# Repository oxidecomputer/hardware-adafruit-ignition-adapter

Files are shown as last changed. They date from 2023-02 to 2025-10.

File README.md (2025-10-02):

# hardware-adafruit-ignition-adapter

## Description

Adapter board for the [Adafruit FT232H](https://www.adafruit.com/product/2264)
compatible with `iceprog` and the Samtec debug pinout we're using on our
designs.

## Ordering Information

Each release contains a file called `[CPN]_release_notes.txt` with ordering
instructions. Order PCBs through Sierra Circuits' [Turnkey
PRO](https://www.protoexpress.com/products/turnkey-pro/) fabrication and
assembly service.

## Release Information

Fabrication data follows the `[CPN]_rev[X]_v[Y]` naming convention, where
revision `rev[X]` and version `v[Y]` corresponds to the two numbers in Altium's
release version. Here's why:

- When we release the board in Altium 365, Altium tags the release with the
  suffix `[X].[Y]`

- However, Sierra Circuits only accepts a single revision number, which appears
  in their ordering system as `_rev[X]`.
  
- When we assemble the tapeout data package together for Sierra Circuits, we
  name the tapeout files `[CPN]_rev[X]_v[Y]` to maintain the mapping between
  Altium release and the out-of-band tapeout data package.

- When we order PCBs through Sierra Circuits, we specify the revision using the
  `[X]` number. This appears in Sierra's order system as `[CPN]_rev[X]`.

Essentially, we ignore the `[Y]` value and we increment the `[X]` in the Altium
release. In practice, however, the `[Y]` value in the Altium release ends up
getting incremented if we have to re-release something in Altium to correct data
export errors before submitting the release for fabrication (for example, to fix
missing drill files in the tapeout data package). If this sounds confusing, it's
because it is.

## Assembly

Follow the [assembly
instructions](https://github.com/oxidecomputer/hardware-adafruit-ignition-adapter/tree/main/assembly)
to assemble a complete Ignition programming dongle.

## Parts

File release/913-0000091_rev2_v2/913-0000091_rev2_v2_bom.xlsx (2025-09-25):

BOM: 913-0000091
Assembly Part Number/Revision: 913-0000091_rev2
Oxide Computer Company
 |  |  | 1
Item # | Quantity per board | Manufacturer Part # | Do Not Install | Reference designators | Vendor (optional) | Vendor Part Number (optional) | Value (optional) | Size / Footprint (optional) | Part description/ specs (optional, but recommended) | Manfacturer (optional)
1 | 1 | GRM155R61E105KA12D |  | C1 | DigiKey | 490-10017-1-ND | 1uF |  | CAP CER 1UF 25V X5R 0402 | Murata Electronics
2 | 2 | 22284110 |  | J1,J2 | DigiKey | WM50014-11-ND |  |  | CONN HEADER VERT 11POS 2.54MM | Molex
3 | 1 | TFC-105-02-L-D-A-K-TR |  | J3 | Mouser | 200-TFC10502LDAKTR |  |  | .050 X .050 TERMINAL STRIP | Samtec
4 | 1 | RMCF0402FT10K0 |  | R1 | Digikey | RMCF0402FT10K0CT-ND | 10k |  | RES 10K OHM 1% 1/16W 0402 | Stackpole
5 | 2 | RMCF0402FT15R0 |  | R2,R3 | Digikey | RMCF0402FT15R0CT-ND | 15 |  | RES 15 OHM 1% 1/16W 0402 | Stackpole
6 | 1 | SN74LVC1G07DCKR |  | U1 | Digikey | 296-8486-1-ND |  |  | IC BUFF NON-INVERT 5.5V SC-70-5 | Texas Instruments
END OF BOM

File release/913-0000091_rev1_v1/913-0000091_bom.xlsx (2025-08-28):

BOM: 913-0000091
Assembly Part Number/Revision: 913-0000091_rev1
Oxide Computer Company
 |  |  | 1
Item # | Quantity per board | Manufacturer Part # | Do Not Install | Reference designators | Vendor (optional) | Vendor Part Number (optional) | Value (optional) | Size / Footprint (optional) | Part description/ specs (optional, but recommended) | Manfacturer (optional)
1 | 11 | GRM155R61E105KA12D |  | C1,C2,C3,C4,C5,C6,C7,C8,C9,C10,C11 | DigiKey | 490-10017-1-ND | 1uF |  | CAP CER 1UF 25V X5R 0402 | Murata Electronics
2 | 7 | UCLAMP3301P.TCT |  | D1,D2,D3,D4,D5,D6,D7 | Mouser | 947-UCLAMP3301P.TCT |  |  | UCLAMP 1 LINE ESD PROTECTION | Semtech
3 | 2 | 22284110 |  | J1,J2 | DigiKey | WM50014-11-ND |  |  | CONN HEADER VERT 11POS 2.54MM | Molex
4 | 1 | TFC-105-02-L-D-A-K-TR |  | J3 | Mouser | 200-TFC10502LDAKTR |  |  | .050 X .050 TERMINAL STRIP | Samtec
5 | 4 | RMCF0402FT10K0 |  | R1,R6,R8,R9 | Digikey | RMCF0402FT10K0CT-ND | 10k |  | RES 10K OHM 1% 1/16W 0402 | Stackpole
6 | 5 | RMCF0402FT15R0 |  | R2,R3,R4,R5,R7 | Digikey | RMCF0402FT15R0CT-ND | 15 |  | RES 15 OHM 1% 1/16W 0402 | Stackpole
7 | 1 | SN74LVC1G07DCKR |  | U1 | Digikey | 296-8486-1-ND |  |  | IC BUFF NON-INVERT 5.5V SC-70-5 | Texas Instruments
8 | 5 | SN74LVC1T45DCKR |  | U2,U3,U4,U5,U6 | Digikey | 296-16844-1-ND |  |  | IC XLTR VL BIDIR SC-70-6 | Texas Instruments
END OF BOM

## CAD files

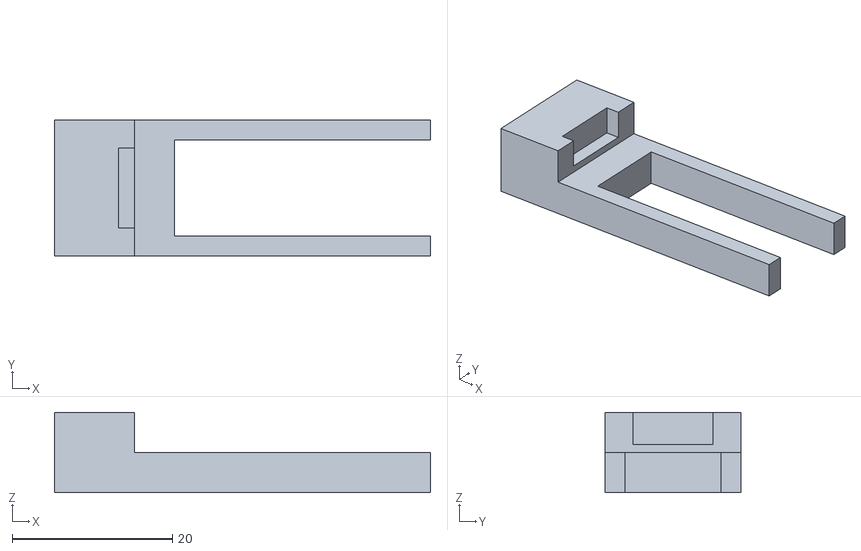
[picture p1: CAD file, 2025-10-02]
assembly/adafruit_soldering_fixture/adafruit_soldering_fixture.stl
47.0 x 17.0 x 10.0

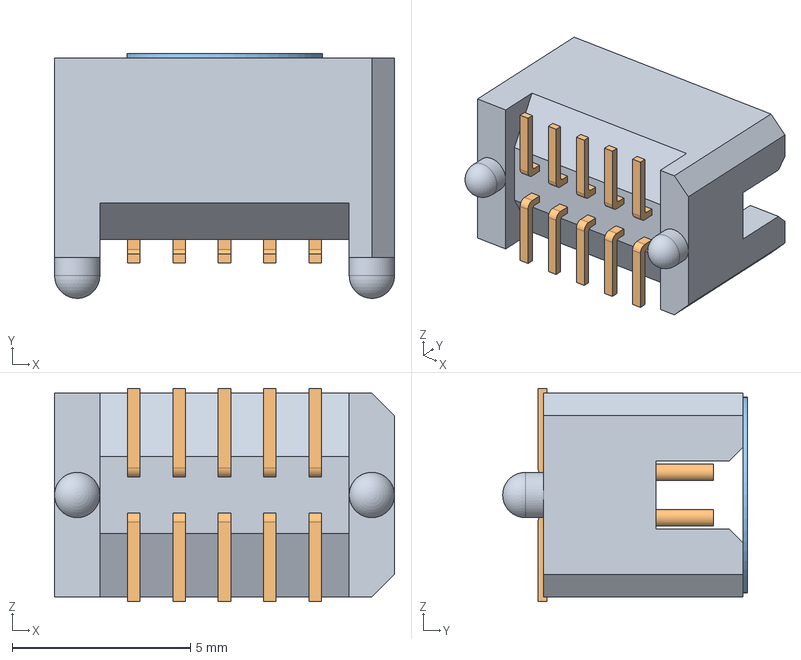
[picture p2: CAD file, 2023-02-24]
release/913-0000091_rev0/TFC-105-02-F-D-A-K.step
9.52 x 6.86 x 5.97 mm
_TFC-105-02-L-D-A-K_terminal
_TFC-105-02-L-D_pins
_TFC-Polyamide_Pad-K_polyamide_pick

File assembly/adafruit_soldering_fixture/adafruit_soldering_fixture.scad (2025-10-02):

// ignition-adapter soldering jig

oversize = 1;


// subtract cutouts for the standoffs, circuits, and USB notch
difference(){
// create the body
cube(size=[40+7,17,10], center=false);
    
// create the standoff cutout
translate([10,-1,5])
    cube(size=[(42+oversize),17+(2*oversize),(5+oversize)], center=false);

// create the circuit clearance cutout
translate([15,2.5,-(oversize)])
    cube(size=[(25+7+oversize),12,5+(2*oversize)], center=false);

// create the usb cutout
translate([8,3.5,6])
    cube(size=[(3+oversize),10,(4+oversize)], center=false);
}

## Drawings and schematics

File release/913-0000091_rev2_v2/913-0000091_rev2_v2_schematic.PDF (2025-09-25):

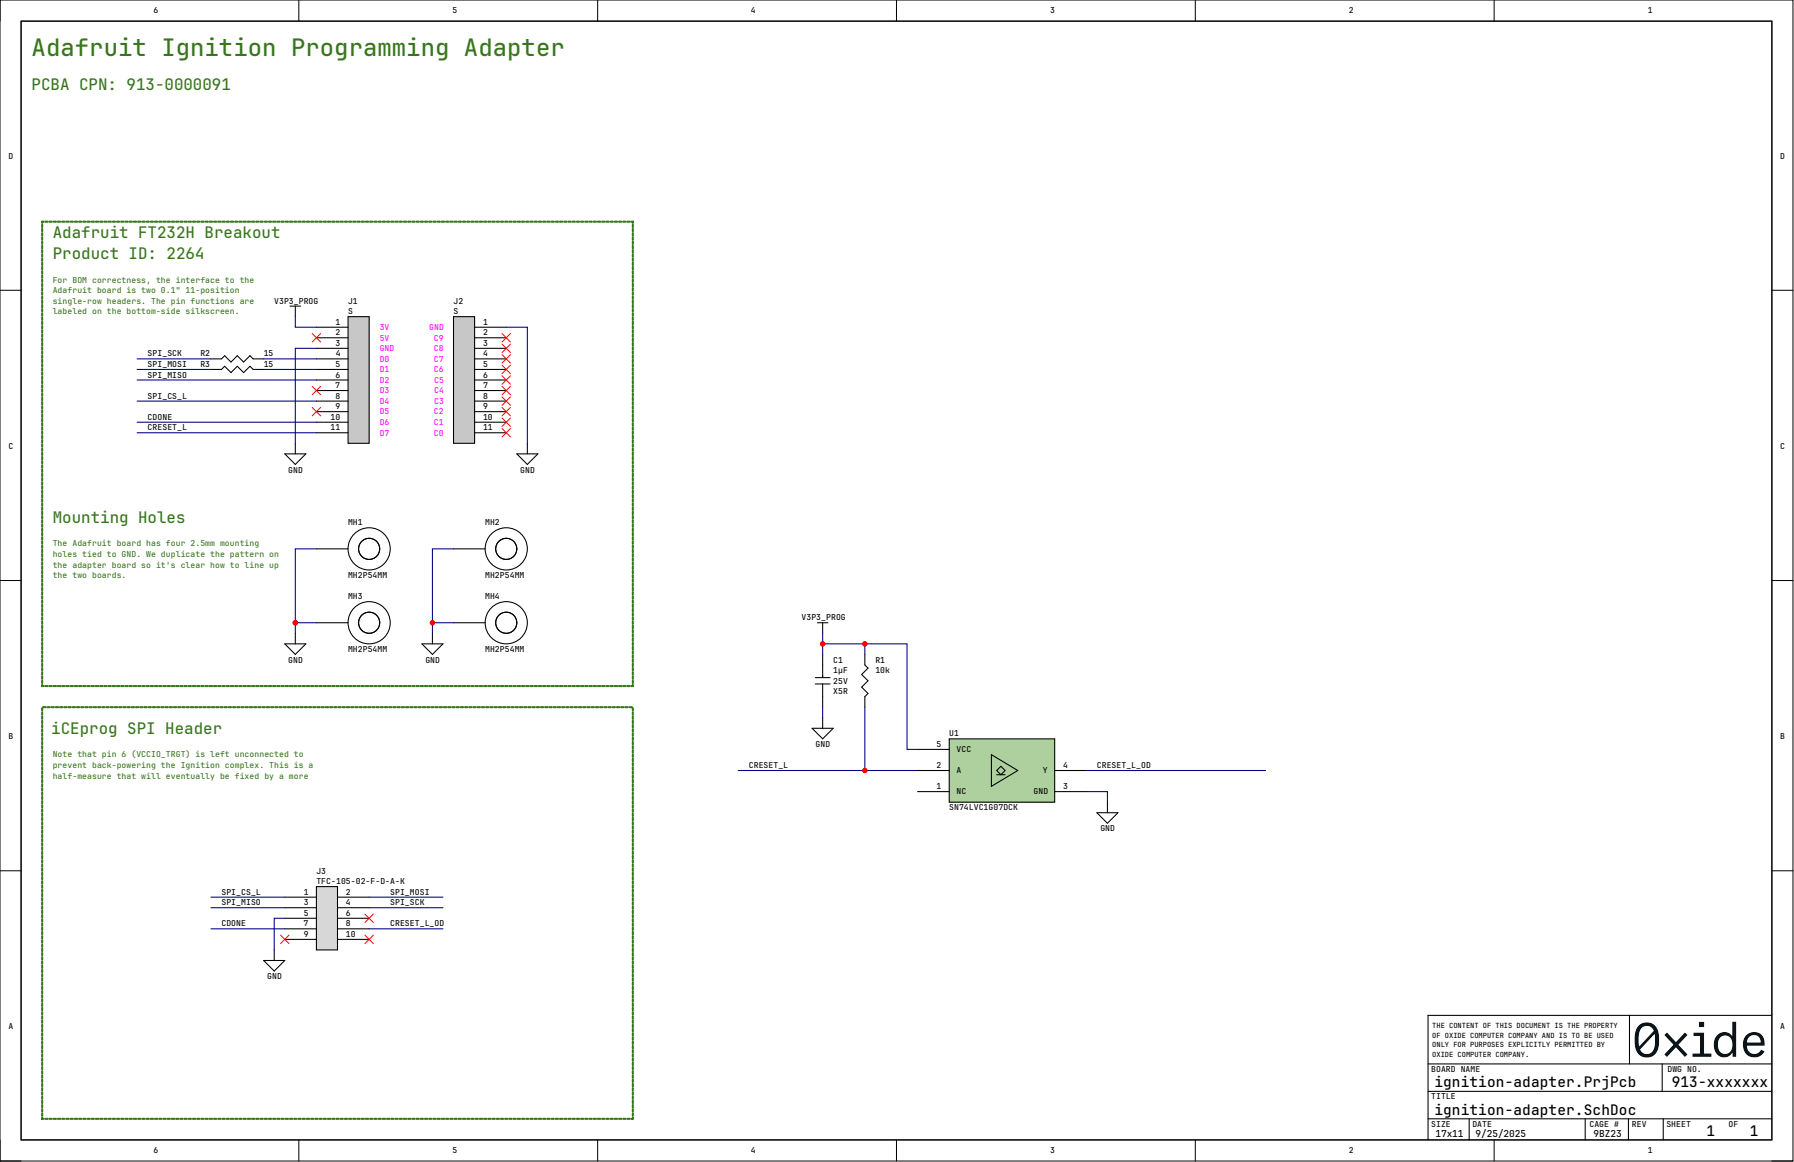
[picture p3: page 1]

Adafruit Ignition Programming Adapter

For BOM correctness, the interface to the
Adafruit board is two 0.1" 11-position
single-row headers. The pin functions are
labeled on the bottom-side silkscreen.

The Adafruit board has four 2.5mm mounting
holes tied to GND. We duplicate the pattern on
the adapter board so it's clear how to line up
the two boards.

Note that pin 6 (VCCIO_TRGT) is left unconnected to
prevent back-powering the Ignition complex. This is a
half-measure that will eventually be fixed by a more

THE CONTENT OF THIS DOCUMENT IS THE PROPERTY OF OXIDE COMPUTER COMPANY AND IS TO BE USED ONLY FOR PURPOSES EXPLICITLY PERMITTED BY OXIDE COMPUTER COMPANY.

BOARD NAME ignition-adapter.PrjPcb | DWG NO. 913-xxxxxxx

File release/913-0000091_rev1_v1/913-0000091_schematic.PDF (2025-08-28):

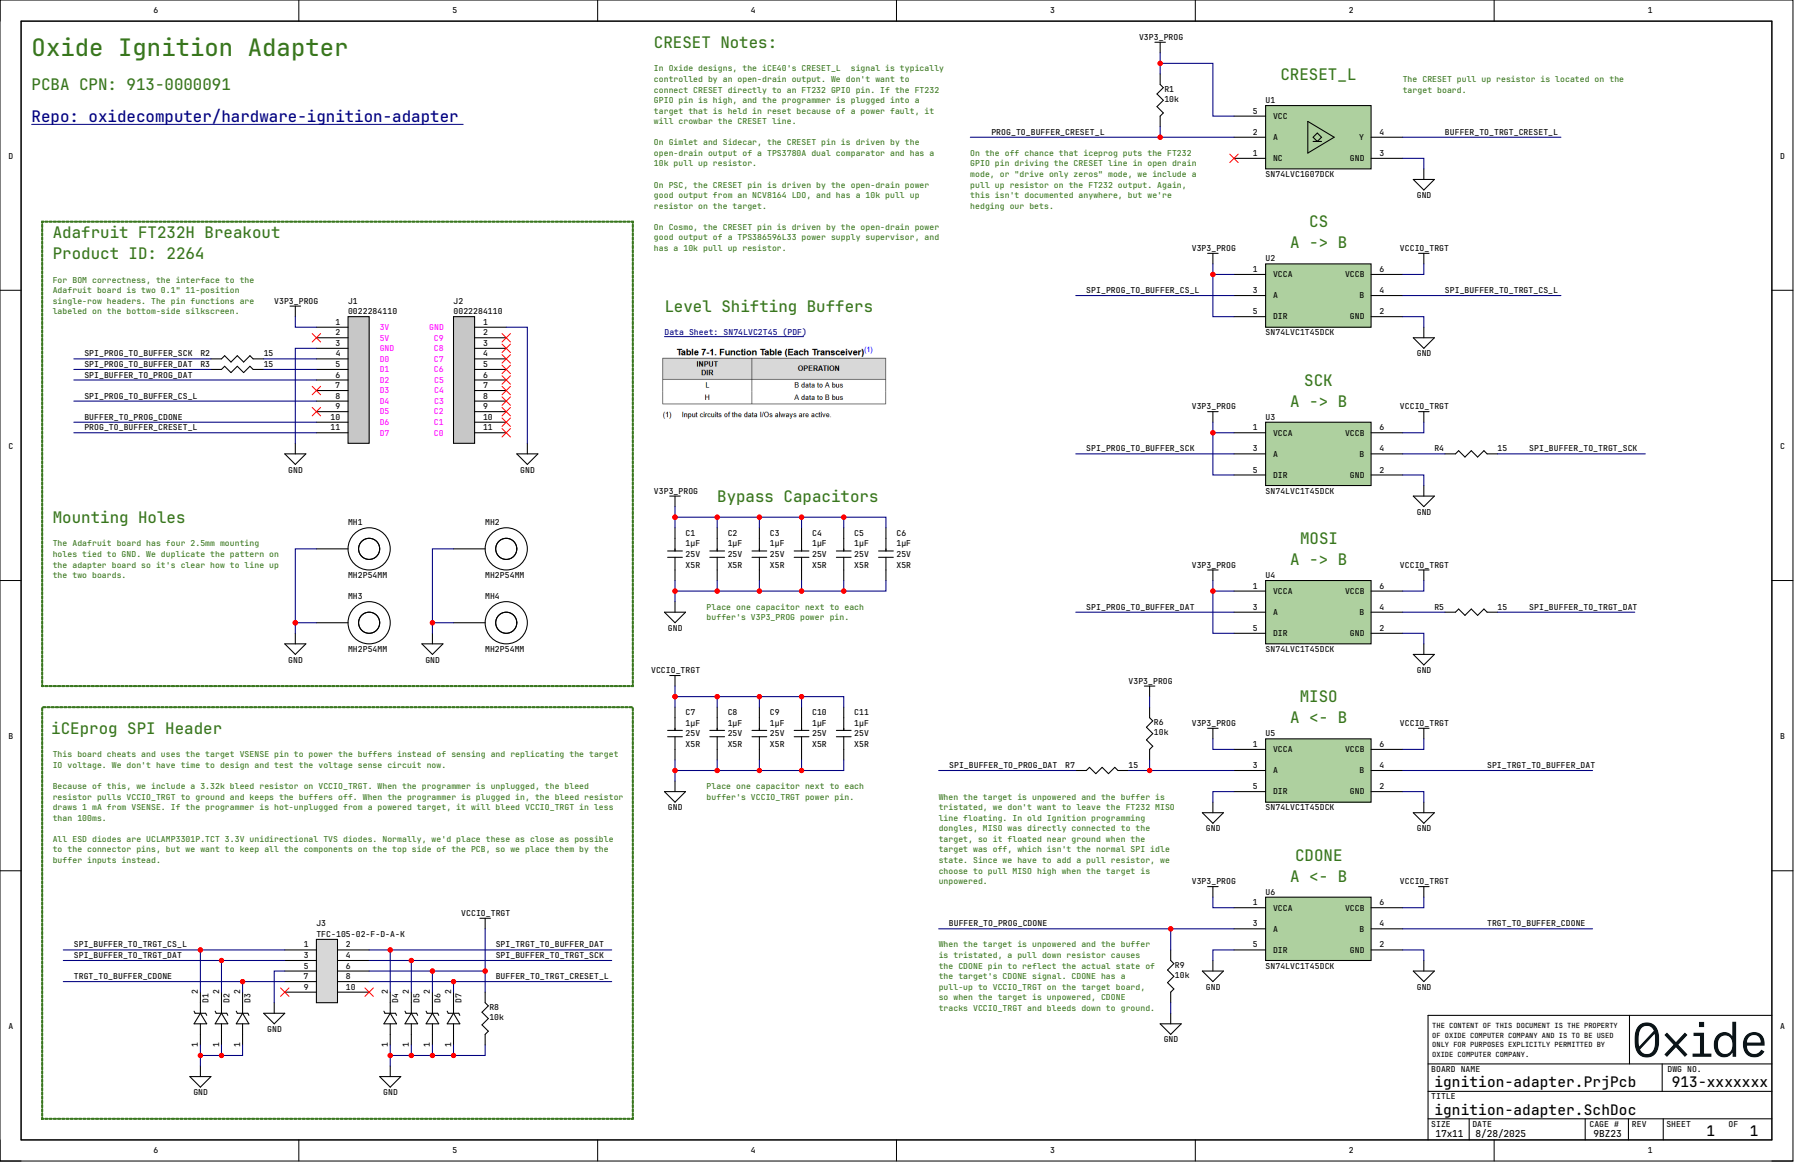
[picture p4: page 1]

In Oxide designs, the iCE40's CRESET_L signal is typically
controlled by an open-drain output. We don't want to
connect CRESET directly to an FT232 GPIO pin. If the FT232
GPIO pin is high, and the programmer is plugged into a
target that is held in reset because of a power fault, it
will crowbar the CRESET line.

PCBA CPN: 913-0000091
Repo: oxidecomputer/hardware-ignition-adapter (https://github.com/oxidecomputer/hardware-ignition-adapter)

The CRESET pull up resistor is located on the
target board.

On Gimlet and Sidecar, the CRESET pin is driven by the
open-drain output of a TPS3780A dual comparator and has a
10k pull up resistor.

On the off chance that iceprog puts the FT232
GPIO pin driving the CRESET line in open drain
mode, or "drive only zeros" mode, we include a
pull up resistor on the FT232 output. Again,
this isn't documented anywhere, but we're
hedging our bets.

On PSC, the CRESET pin is driven by the open-drain power
good output from an NCV8164 LDO, and has a 10k pull up
resistor on the target.

On Cosmo, the CRESET pin is driven by the open-drain power
good output of a TPS386596L33 power supply supervisor, and
has a 10k pull up resistor.

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

Place one capacitor next to each
buffer's V3P3_PROG power pin.

This board cheats and uses the target VSENSE pin to power the buffers instead of sensing and replicating the target
IO voltage. We don't have time to design and test the voltage sense circuit now.

Because of this, we include a 3.32k bleed resistor on VCCIO_TRGT. When the programmer is unplugged, the bleed
resistor pulls VCCIO_TRGT to ground and keeps the buffers off. When the programmer is plugged in, the bleed resistor
draws 1 mA from VSENSE. If the programmer is hot-unplugged from a powered target, it will bleed VCCIO_TRGT in less
than 100ms.

buffer's VCCIO_TRGT power pin.

When the target is unpowered and the buffer is
tristated, we don't want to leave the FT232 MISO
line floating. In old Ignition programming
dongles, MISO was directly connected to the
target, so it floated near ground when the
target was off, which isn't the normal SPI idle
state. Since we have to add a pull resistor, we
choose to pull MISO high when the target is
unpowered.

All ESD diodes are UCLAMP3301P.TCT 3.3V unidirectional TVS diodes. Normally, we'd place these as close as possible
to the connector pins, but we want to keep all the components on the top side of the PCB, so we place them by the
buffer inputs instead.

When the target is unpowered and the buffer
is tristated, a pull down resistor causes
the CDONE pin to reflect the actual state of
the target's CDONE signal. CDONE has a
pull-up to VCCIO_TRGT on the target board,
so when the target is unpowered, CDONE
tracks VCCIO_TRGT and bleeds down to ground.

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

BOARD NAME ignition-adapter.PrjPcb | DWG NO. 913-xxxxxxx

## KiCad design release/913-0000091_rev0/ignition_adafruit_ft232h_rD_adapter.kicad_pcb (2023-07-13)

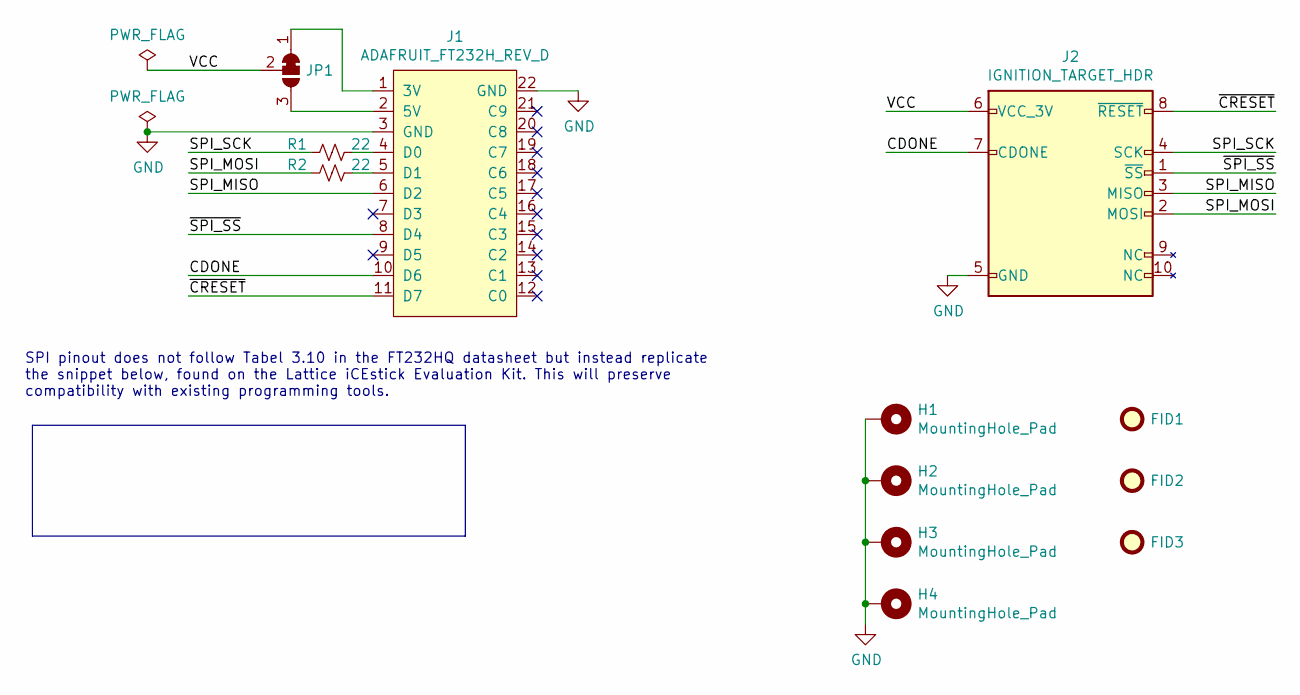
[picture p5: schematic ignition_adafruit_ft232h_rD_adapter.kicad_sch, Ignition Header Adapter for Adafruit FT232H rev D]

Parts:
FID1, FID3: Fiducial; Fiducial_0.5mm_Mask1mm
FID2: iCE40 Adapter; Oxide_Board_Identifier_23x6mm
H1, H2, H3, H4: MountingHole_Pad; MountingHole_100mils_Pad
J1: ADAFRUIT_FT232H_REV_D; ADAFRUIT_FT232H_REVD
J2: IGNITION_TARGET_HDR; TFC-105-02-F-D-A-K
JP1: SolderJumper_3_Bridged12; SolderJumper-3_P1.3mm_Bridged12_Pad1.0x1.5mm
R1, R2: 22; R_0603_1608Metric

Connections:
/CDONE: J1.10 (D6), J2.7 (CDONE)
/SPI_MISO: J1.6 (D2), J2.3 (MISO)
/SPI_MOSI: J2.2 (MOSI), R2.2
/SPI_SCK: J2.4 (SCK), R1.2
/VCC: J2.6 (VCC_3V), JP1.2 (C)
/~CRESET: J1.11 (D7), J2.8 (~RESET)
/~SPI_SS: J1.8 (D4), J2.1 (~SS)
GND: H1.1, H2.1, H3.1, H4.1, J1.3 (GND), J1.22 (GND), J2.5 (GND)
unnamed: J1.1 (3V), JP1.1 (A)
unnamed: J1.2 (5V), JP1.3 (B)
unnamed: J1.4 (D0), R1.1
unnamed: J1.5 (D1), R2.1

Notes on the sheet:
SPI pinout does not follow Tabel 3.10 in the FT232HQ datasheet but instead replicate the snippet below, found on the Lattice iCEstick Evaluation Kit. This will preserve compatibility with existing programming tools.

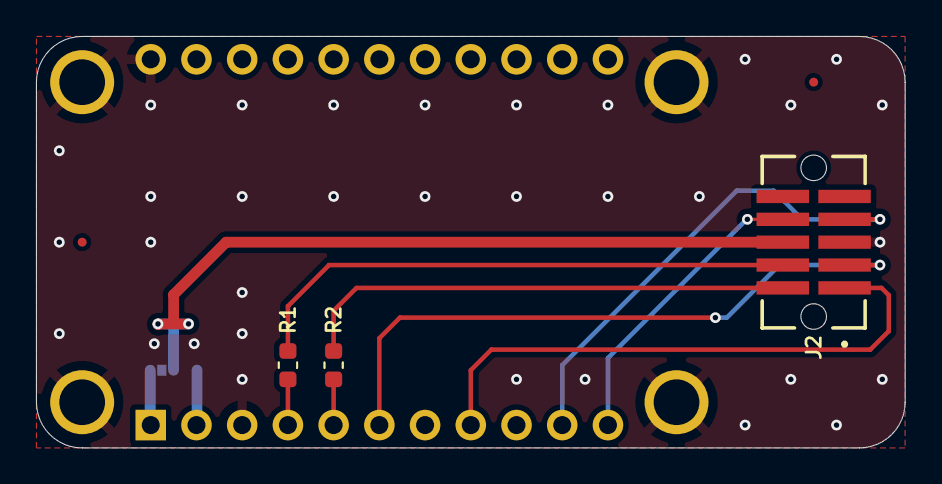
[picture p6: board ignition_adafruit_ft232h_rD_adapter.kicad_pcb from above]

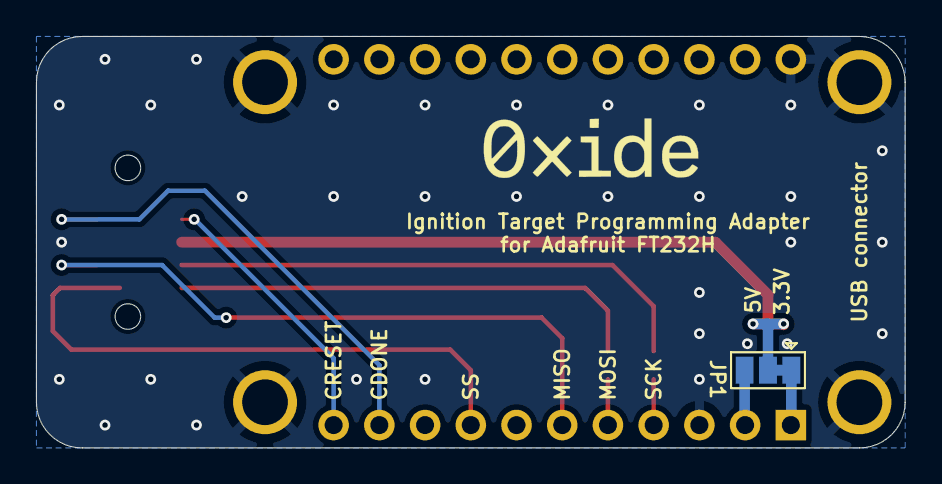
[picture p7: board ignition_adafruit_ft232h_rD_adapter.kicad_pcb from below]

Board: 4 copper layers, 48.3 x 22.9 mm, 12 parts (2 on the bottom side), 12 nets.

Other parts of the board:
Ref**: Val**; OXIDE_Wordmark

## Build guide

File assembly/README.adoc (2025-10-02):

= Ignition Programming Dongle Assembly Instructions

== Materials

- One (1) 913-0000089 Adafruit FT232H breakout board (Adafruit Product ID [2264](https://www.adafruit.com/product/2264))
- One (1) 913-0000091 Adafruit Ignition Adapter PCBA
- One (1) 920-0000116 Ignition Programming Cable (Samtec SFSD-05-28-G-3.25-D-NDX)
- 1-inch diameter adhesive-lined heat shrink tubing with a 3:1 shrink ratio
- X-Acto knife or scalpel
- Superglue
- Heat gun
- Brother PTouch PT-P700 printer
- Brother TZE 9mm black-on-white label tape
- Dymo Rhino 4200 label maker
- Dymo A18057 19mm heat shrink label tube
- (Optional) One 3D-printed https://github.com/oxidecomputer/hardware-adafruit-ignition-adapter/tree/main/assembly/adafruit_soldering_fixture[Adafruit soldering fixture]

== Assembly

. Remove the Adafruit FT232H breakout board from its package. Confirm that the
`I2C MODE` switch on the Adafruit FT232H breakout board is set to `OFF`.

. Slide the Adafruit FT232H breakout board onto the headers installed on the
Ignition adapter board as shown in Figure X. If you're assembling lots of these
dongles, we recommend using the 3D-printed
https://github.com/oxidecomputer/hardware-adafruit-ignition-adapter/tree/main/assembly/adafruit_soldering_fixture[Adafruit
soldering fixture] to achieve consistent alignment.

. Solder the Adafruit Ignition adapter board to the Adafruit FT232H breakout
board.

. Cut a 2-inch length of 1-inch diameter heat shrink tubing and shrink wrap the
entire PCBA, including the connectors, as shown in Figure X.

. Once the heat shrink has cooled and hardened completely, cut the heat shrink
away from the Ignition programming connector with an X-Acto knife or scalpel as
shown in Figure X.

. Plug in the SFSD-05-28-G-10.00-D-NDX cable to connector J3 and apply a dot of
superglue at the joint between the connector and the cable to secure the cable
in place.

== Flashing the FT232 EEPROM

For some reason, https://forums.adafruit.com/viewtopic.php?t=147113[Adafruit
programs all their FT232H breakout board EEPROMs with identical, invalid EEPROM
images]. Oxide's manufacturing stations identify dongles by serial number, so we
use a Python script to generate a random serial number and flash the EEPROM with
a valid image. The Python script also prints out a serial number label for the
dongle so we can identify it during programming station setup.

Dependencies:

- `python3`
- `ftdi-eeprom`
- `ptouch-print` (manually built following [these instructions](https://github.com/HenrikBengtsson/brother-ptouch-label-printer-on-linux))

Clone the [oxidecomputer/hardware-toolbox
](https://github.com/oxidecomputer/hardware-toolbox)repo and run
`adafruit-fix.py`.

```
$ git clone https://github.com/oxidecomputer/hardware-toolbox
$ cd hardware-toolbox/adafruit-programming
$ python3 adafruit_fix.py
```

See `$ python3 adafruit_fix.py --help` for a list of optional arguments.

Running `adafruit_fix.py` will generate a random serial number, program the
FT232 EEPROM, and print a label with the serial number. Apply the serial number
to the bottom of the dongle as shown in Figure X.

== Labels

Each Ignition programming dongle needs two labels:

- A label on the dongle with the FT232 serial number. Running `adafruit_fix.py`
prints this label automatically

- A label on the programming cable, to help operators identify which dongle is
which. Print the ceble label on 19mm Dymo heat shrink label tape in 12pt font
and apply it to the ignition cable:

```
IGNITION SPI
920-0000116
```

Apply the labels to the dongle and the cable as shown in Figure X:

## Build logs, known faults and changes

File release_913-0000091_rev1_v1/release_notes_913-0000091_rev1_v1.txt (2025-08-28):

================================================================================
RELEASE NOTES - 913-0000090_rev1_v1
================================================================================

The release package contains three sets of files:

- The release notes (this document)
- A PDF of the schematic
- A bill of materials (BOM) structured in the Sierra Circuits format
- A zipped archive containing the Gerber files, drill files, and pick-and-place
coordinate files that was submitted to the fabricator.

We're fabricating this PCB with Sierra Circuits Turnkey Pro PCB service
https://www.protoexpress.com/

--------------------------------------------------------------------------------
NOTE: Because Benchmark Electronics recieves this board fully assembled, we
treat it as a PCBA in Duro. We don't have separate CPNs for the PCB and the
PCBA. When Sierra Circuits asks us for a Part Number for the PCB and
a part number for the assembly, we use the 913-0000100 CPN for both the PCB
and the assembly.
--------------------------------------------------------------------------------

--------------------------------------------------------------------------------
NOTE: This is actually revision 2 of the board, but in Duro, this is revision 1.
Benchmark expects to see 913-000090_rev1, so that's what we give it.
--------------------------------------------------------------------------------

================================================================================
Fabrication Notes
================================================================================

Here's the information to plug into the Sierra Circuits quote tool:

PCB Part Number = 913-0000090
Revision = 1
[x] Keep the ASSY Part # same as the PCB Part #
Layers = 4 Layer
Board Thickness = 0.062 in
Minimum Trace or Space = 0.007 in (the smallest space in the design is 0.2mm/7.87mils)
Surface Finish = ENIG
Board Dimensions = 43mm x 62mm (1.69 in x 2.44 in)
minimum hole size = 0.010 inches or more (it's 0.4mm/15 mils)
number of holes per board = 200 (approximate)
aseembly on = Both Sides
quantity = 25 assembled PCBs
turn time = 10 days

================================================================================
BOM Notes:
================================================================================

Most of the components we use at Benchmark are currently out of stock at
all suppliers, including our 1uF cap and green LED.

- The green LED was replaced with the VLMG1500-GS08, and I added a silkscreen
marking on the PCB to indicate the cathode pin. However, if this LED is rotated,
it won't impact proper operation.

There are no DNI parts in this design, which makes the BOM easy.

We replaced the 10uF tantalum cap with a 1206 part. See https://github.com/oxidecomputer/hardware-donglet/issues/1

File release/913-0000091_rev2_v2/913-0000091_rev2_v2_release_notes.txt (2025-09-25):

================================================================================
RELEASE NOTES - 913-0000091_rev2_v1

CHANGES:

- Fixed https://github.com/oxidecomputer/hardware-ignition-adapter/issues/11
- Fixed https://github.com/oxidecomputer/hardware-ignition-adapter/issues/10
- Changed the board from 4 layers to 2 layers to reduce cost
- Fixed unoptimized CRESET_L route
================================================================================

The release package contains three sets of files:

- The release notes (this document)
- A PDF of the schematic
- A bill of materials (BOM) structured in the Sierra Circuits format
- A zipped archive containing the Gerber files, drill files, and pick-and-place
coordinate files that was submitted to the fabricator.

We're fabricating this PCB with Sierra Circuits Turnkey Pro PCB service
https://www.protoexpress.com/

================================================================================
Fabrication Notes
================================================================================

Here's the information to plug into the Sierra Circuits quote tool:

PCB Part Number = 913-0000091
Revision = 2
[x] Keep the ASSY Part # same as the PCB Part #
Layers = 2 Layer
Board Thickness = 0.062 in
Minimum Trace or Space = 0.010 in 
Surface Finish = ENIG
Board Dimensions = 2.0 in x 0.9 in
minimum hole size = 0.010 in
number of holes per board = 100 (approximate)
aseembly on = One Side
quantity = 30 assembled PCBs
turn time = 5 days

================================================================================
BOM Notes:
================================================================================

There are no DNI parts in this design, which makes the BOM easy.

Allow Sierra to replace caps and resistors with their preferred components.

================================================================================
Releasing Process
================================================================================
This project is in Altium, so we have a sligtly different release process.

- Generate the files in Altium and release them
- Use the altium web viewer to download the source files
- Rename the source files, if required
- Zip the gerbers
- Submit them to Sierra Circuits
- Copy the release files you downloaded into the github repo and push them
- In Github, create a release using those files.

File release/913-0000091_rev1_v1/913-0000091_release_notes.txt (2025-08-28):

================================================================================
RELEASE NOTES - 913-0000091_rev1_v1
================================================================================

The release package contains three sets of files:

- The release notes (this document)
- A PDF of the schematic
- A bill of materials (BOM) structured in the Sierra Circuits format
- A zipped archive containing the Gerber files, drill files, and pick-and-place
coordinate files that was submitted to the fabricator.

We're fabricating this PCB with Sierra Circuits Turnkey Pro PCB service
https://www.protoexpress.com/

--------------------------------------------------------------------------------
NOTE: Because Benchmark Electronics recieves this board fully assembled, we
treat it as a PCBA in Duro. We don't have separate CPNs for the PCB and the
PCBA. When Sierra Circuits asks us for a Part Number for the PCB and
a part number for the assembly, we use the 913-0000100 CPN for both the PCB
and the assembly.
--------------------------------------------------------------------------------

--------------------------------------------------------------------------------
NOTE: This is actually revision 2 of the board, but in Duro, this is revision 1.
Benchmark expects to see 913-000090_rev1, so that's what we give it.
--------------------------------------------------------------------------------

================================================================================
Fabrication Notes
================================================================================

Here's the information to plug into the Sierra Circuits quote tool:

PCB Part Number = 913-0000091
Revision = 1
[x] Keep the ASSY Part # same as the PCB Part #
Layers = 4 Layer
Board Thickness = 0.062 in
Minimum Trace or Space = 0.007 in (the smallest space in the design is 0.2mm/7.87mils)
Surface Finish = ENIG
Board Dimensions = 1.9in x 0.9in
minimum hole size = 0.009 (it's 0.25mm vias, 9.842mil)
number of holes per board = 100 (approximate)
aseembly on = One Sides
quantity = 30 assembled PCBs
turn time = 10 days

================================================================================
BOM Notes:
================================================================================

There are no DNI parts in this design, which makes the BOM easy.

Allow Sierra to replace caps and resistors with their preferred components.

================================================================================
Releasing Process
================================================================================
This project is in Altium, so we have a sligtly different release process.

- Generate the files in Altium and release them
- Use the altium web viewer to download the source files
- Rename the source files, if required
- Zip the gerbers
- Submit them to Sierra Circuits
- Copy the release files you downloaded into the github repo and push them
- In Github, create a release using those files.

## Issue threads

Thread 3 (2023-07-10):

Check thermal reliefs on through hole ground pins and mounting holes

isobering, 2023-07-10:
J1 pin 3, J1 pin 22, and mounting holes M1-M4 have solid connections to ground on outer layers, but have thermal reliefs on inner layers. The ground planes on top and bottom are about as large as the ground planes on inner layers. Should these pins use thermal reliefs on all layers?

Closed 2023-07-13.

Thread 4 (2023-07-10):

Consider increasing trace widths from 7 mils to ~10 mils

isobering, 2023-07-10:
Consider increasing the default trace width from 7 mils to 10 mils. This may be a layout preference issue, but if we have room, wider traces are better for manufacturing and lower inductance.

Closed 2023-07-13.

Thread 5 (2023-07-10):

Consider reducing the length of the `CDONE` and `CRESET` traces

isobering, 2023-07-10:
Here's the original routing:

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

Here's an option that makes `CDONE` and `CRESET` significantly shorter:

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

Closed 2023-07-13.

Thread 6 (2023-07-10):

Consider making the `VCC` trace wider or using a wide copper shape

isobering, 2023-07-10:
Since there's room on the PCB, consider making the `VCC` trace a large copper shape/plane on the top layer.

EDIT - there's also some inconsistency with ground return vias at both ends of the `VCC` trace. There are two ground return vias on either side of `VCC` next to jumper JP1, but there aren't any ground return vias where `VCC` terminates into J2. Either we need ground return vias on both ends of the trace, or we should remove them.

I suspect that ground return vias are overkill in this design because our data rates are slow enough that the ground via/pin in J2 and the ground pin in J1 (pin 3) are sufficient. So if you want to get some layout room back, you can probably delete the ground return vias on either side of the `VCC` trace by JP2.

nathanaelhuffman, 2023-07-10:
So most of our designs don't use any power to/from the target at all here so I think this is mostly a don't care.  I did notice some acute angles coming out of the jumper so I adjusted those to be right-angle.

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

Closed 2023-07-13.

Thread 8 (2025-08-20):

Ignition adapter passes 3.3V power to target and back-powers A3 domain

isobering, 2025-08-20:
In https://github.com/oxidecomputer/hardware-cosmo/issues/740, we noticed that connecting an Ignition dongle to a target Cosmo will back-power the Ignition complex enough that the FPGA can configure itself from flash.

On the target side of the programming interface, Oxide boards connects the 3.3V Ignition power supply rail to pin 6 of the Ignition programming header (or to pin 6 of the Oxide Programming Adapter connector). The assumption is that the programmer uses this pin to sense and replicate the target IO voltage.

However, the hw-ignition-adapter PCB connects the Adafruit dongle's 3.3V power rail to pin 6 of the Ignition target programming connector through a jumper. This wires the ignition programmer power directly to the target power:

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

We need to disconnect Adafruit power from Ignition target power for proper operation. Here are some potential solutions:

- Clip the wire in position 6 of the Ignition programming cable. This requires someone at either Oxide or Benchmark to manually cut these cables, and it means we can't use them for other applications.
- Cut the power supply select jumper on the hw-ignition-adapter PCB. We could do this as an MCN and have someone at Oxide or Benchmark manually cut all the jumpers.
- Update the hw-ignition-adapter PCB CAD to delete the jumper and leave pin 6 of the Ignition programming header unconnected. This requires no manual intervention but is probably ~1 day of work to redraw the PCB in Altium.

**EDIT:** Note that, while these options will prevent the dongle from back-powering the board through the power pin, it won't stop the FT232 from partially back-powering the board through the SPI lines unless we implement some manufacturing software updates to tristate the FT232 pins whenever the Meanwell is off. A fourth option is to add level-shifting buffers to the hw-ignition-adapter PCB, which will fix the back-driving issues entirely.

I think it's worth fixing this now because we're about to build ~20 of these for Minibar programming stations, and back-powering the Ignition domain causes weird programming behavior.

isobering, 2025-08-20:
If we can find a COTS adapter with target isolation, I'm all for that. The trick is that, while there are COTS dongles that claim they do SPI, `iceprog` doesn't use the default MPSSE SPI pinout from table 3.10 of the FT232 data sheet. Instead, they treat the interface like a custom serial interface. Two GPIO pins are required for the iCE40's CRESET and CDONE signals, and for some reason, they move the chip select line to a GPIO pin as well. Here's the pinout `iceprog` expects to see (taken from the Lattice iCEStick Evaluation Kit):

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

Note that when you're looking at table 3.10 in the FT232 data sheet, the pin numbers in the table are for the FT232H, not the FT232HQ...aargh.

The differences are:

- Chip select is on `ADBUS4` (`GPIOL0`) instead of `ADBUS3` (`CS`)
- The programmer has to break out `ADBUS61 and `ADBUS7` to the target.

Again, if we can find a programmer that breaks these out, that's great, but I can't find an internal pinout for the JTAG-HS2 to confirm that it exposes those pins.

isobering, 2025-08-28:
In the end, we opted to redo this board in Altium and add level-shifting buffers between the programmer (the Adafruit board) and the target. We use the Adafruit board's 3.3V power pin to power the A side of the buffers, and we use the target's VCCIO pin to power the B side of the buffers.

Normally, I don't like powering the buffers from the target board, but we need to get this board out as quickly as possible. Future Oxide programmers will include a circuit to sense and replicate the target voltage instead of drawing power from the programming connector.

This is fixed in the new design (913-0000090 rev1). See the project schematic for more information.

Closed 2025-08-28.

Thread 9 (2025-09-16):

Missing silkscreen indicators for J1 and J2

isobering, 2025-09-16:
J1 and J2 are missing silkscreen labels on the top side silkscreen. This draws a TQ from Sierra every time we submit it.

isobering, 2025-10-02:
There isn't room to add these on the top silkscreen because of the text we added labeling Adafruit pin names and functions. It's not worth spending more time to fix this. Closing as not planned.

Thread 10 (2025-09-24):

MISO and MOSI lines are swapped

isobering, 2025-09-24:
When attempting to flash an Ignition target FPGA bitstream to a PSC version B, `iceprog` flash operation would hang in the "waiting" state until it timed out. I grabbed one of the original Ignition programming dongles, and the PSC flashed successfully. After inspecting the schematic, I noticed that the SPI data lines were swapped on the adapter PCB.

In the original Ignition programming dongle:

- Adafruit pin D1 is called `SPI_MOSI` and connects to TFC pin 2
- Adafruit pin D2 is named `SPI_MISO` and connects to TFC pin 3

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

In this design:

- Adafruit pin D1 is `SPI_PROG_TO_TRGT_DAT` and connects to TFC pin 3
- Adafruit pin D2 is `SPI_TRGT_TO_PROG_DAT` and connects to TFC pin 2

Note that, because we have buffers, the net names change on either side of the buffer, but the direction is consistent. Just replace `BUFFER` with `PROG` or `TRGT`.

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

So regardless of the net names, the data lines are swapped. I reworked the board by cutting the MISO and MOSI traces and swapping them with 30 AWG jumper wire. I was then able to flash the Ignition target image.

**Actions:** Swap the data lines in the schematic.

Closed 2025-10-02.

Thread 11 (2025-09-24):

Target power supply rail sags on the adapter board during Flash verification

isobering, 2025-09-24:
After reworking an adapter board to fix #10, `iceprog` successfully flashed a PSC Ignition target FPGA image, but failed to verify the image. During the verification step, `iceprog -v` prints visibly different blocks of data.

I immediately unplugged the new dongle and connected an old dongle. Running `iceprog -v -c` (compare only) successfully validates the image I wrote with the new dongle. So the issue is not with programming, only with verification.

I scoped the SPI data lines and noticed two things:

- The MISO line (i.e., target to programmer data) is extremely active at beginning and the end of the readback operation
- The SPI data lines turn into runt pulses at the end of the verification step

This means there's a power supply problem. I scoped `VCCIO_TRGT` on the adapter PCB and observed that the power supply droops to about 2V during programming and verification when the buffers are active and below 1.5V at the end of verification, which is low enough to cause the buffers to tristate both outputs. When the buffer outputs are tristated, the programmer will read all ones

Note that this image is taken with an additional 10uF bulk bypass capacitor already soldered on the adapter PCB:

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

By soldering a 10uF bulk bypass capacitor, the programmer was able to flash and verify the image 75% of the time. With a 10uF capacitor, `VCCIO_TRGT` sags to just over 1.5V, and depending on the noise on the PCB, the buffers UVLO may or may not trip.

Context:

This was supposed to be a quick-turn PCB. We made the decision to power the target side of the buffers over the Ignition cable knowing it was a half measure at the time, but wanting to reduce cost and risk. At the time, we thought we wouldn't have enough time to test a reference voltage generation circuit. It looks like we don't have enough bypass capacitance to compensate for the cable inductance.

**EDIT 1: This is not I-R drop over the cable, which has a resistance of about 0.2 Ohms.**

**EDIT 2: The 3.3V Ignition power rail is stable on the PSC while this is happening (i.e., this isn't target voltage droop).**

isobering, 2025-09-24:
I'm also noticing that `iceprog` reports `cdone = LOW` when flashing completes when using the new dongle, and `cdone = HIGH` when flashing completes with the old dongle, and with the new dongle, the PSC remains in A3 after flashing instead of proceeding to A2.

This may or may not be power supply related, but it changes the behavior of the manufacturing test station, and we don't want that.

To check if this is power supply related, I jumpered the Adafruit's 3.3V rail to TFC connector pin 6, essentially giving us the same configuration we had with the old dongle. Now, the dongle reliably flashes and verifies every time, but `iceprog` still reports `cdone = LOW`.

What I am now realizing is happening is that `iceprog` is tristating all of its pins when programming is complete and it releases `CRESET_L` to prevent the dongle from crowbarring the SPI bus. Apparently, I forgot this when I tried to make a PCB in 24 hours. However, the buffers aren't tristating their outputs, too, so we're locking up the SPI bus and preventing the Ignition target from configuring after flashing.

So we've fixed the back-powering problem, but we've created a new problem where we prevent the programming operation from proceeding.

Because we're dependent on `iceprog`, fixing this is going to require a much bigger architectural change than we have the ability to perform right now. We need a way to tristate the buffer outputs when CRESET is released. If we had a reference voltage generation circuit on the board, we could probably hack together something where asserting CRESET pulls the reference voltage output to ground and tristates the buffers, but we don't.

If we had an inverter or an nfet lying around, we could use an inverted copy CRESET_L to control the buffers' direction inputs and switch the `SCK`, `CS`, and `MOSI` buffers to inputs when the FPGA is released from reset. That would prevent the dongle from crowbarring the bus. I'll check my stock and see if I have any.

However, in the long run, I think the solution is going to be:

- Delete the buffers
- Leave pin 6 unconnected on the adapter board and do not sense the target voltage.
- Let `iceprog` do whatever it wants with the pin configuration

because that's what works.

Closed 2025-10-02.

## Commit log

2023-02-24 Initial commit of restructured design
    [TFC-105-02-F-D-A-K.step, ignition_adafruit_ft232h_rD_adapter.kicad_pcb, ignition_adafruit_ft232h_rD_adapter.kicad_sch]
2023-07-10 Fixes #1, Fixes #3
    [ignition_adafruit_ft232h_rD_adapter.kicad_pcb]
2023-07-10 Fixes #5, Fixes #4
    [ignition_adafruit_ft232h_rD_adapter.kicad_pcb]
2025-08-28 restructured project and added bom
    [TFC-105-02-F-D-A-K.step, bom_913-0000091_rev1_v1.xlsx, ignition_adafruit_ft232h_rD_adapter.kicad_pcb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]
2025-08-28 added release files
    [913-0000091_bom.xlsx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]
2025-08-28 renamed release files for consistency
    [913-0000091_bom.xlsx]
2025-08-29 added missing drill files and regenerated TDP
    [913-0000091_bom.xlsx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]
2025-09-25 released rev2 v2
    [913-0000091_rev2_v2_bom.xlsx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]
2025-10-02 created first-pass assembly instructions and restructured release files
    [913-0000091_bom.xlsx, 913-0000091_rev2_v2_bom.xlsx, TFC-105-02-F-D-A-K.step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]
2025-10-02 updating ordering and release information
    [adafruit_soldering_fixture.scad, adafruit_soldering_fixture.stl]
2025-10-02 updated assembly instructions

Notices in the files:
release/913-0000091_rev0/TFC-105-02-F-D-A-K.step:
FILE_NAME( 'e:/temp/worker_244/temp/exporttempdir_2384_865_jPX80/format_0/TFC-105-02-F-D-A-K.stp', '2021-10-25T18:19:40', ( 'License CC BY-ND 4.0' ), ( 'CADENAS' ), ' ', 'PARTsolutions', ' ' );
